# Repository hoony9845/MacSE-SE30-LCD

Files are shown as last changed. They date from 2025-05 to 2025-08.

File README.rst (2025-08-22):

MacSE-SE30-LCD
====================================================================

Links
-------
video: https://youtu.be/YyA7AwdUPjI

Reference
-------
https://github.com/aeberbach/MacSE-SE30-analog-replacement

https://github.com/guruthree/mac-se-video-converter

https://tinkerdifferent.com/threads/a-new-alternative-for-high-quality-video-output-on-your-compact-mac.3890/

Pictures
----------

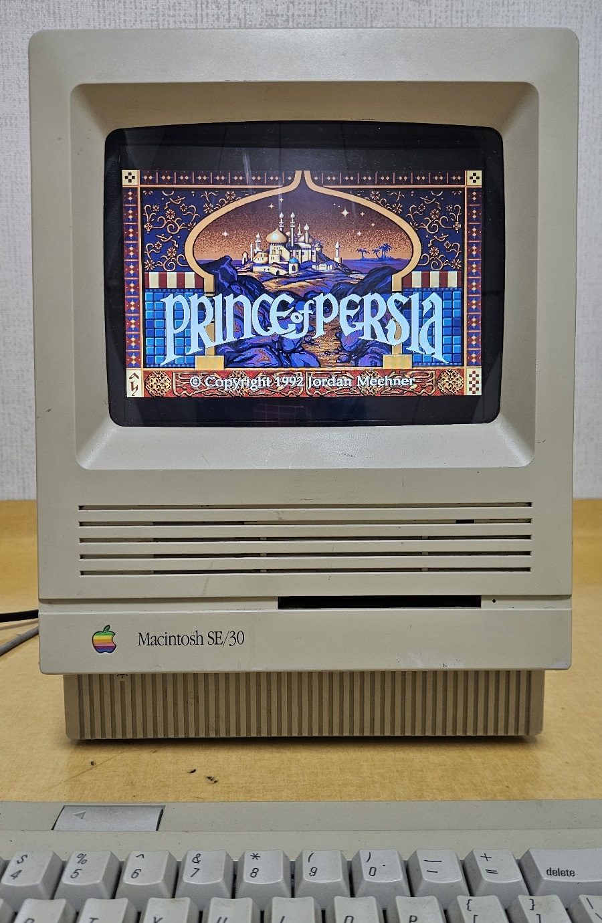
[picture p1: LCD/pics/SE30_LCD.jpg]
 

LCD
----
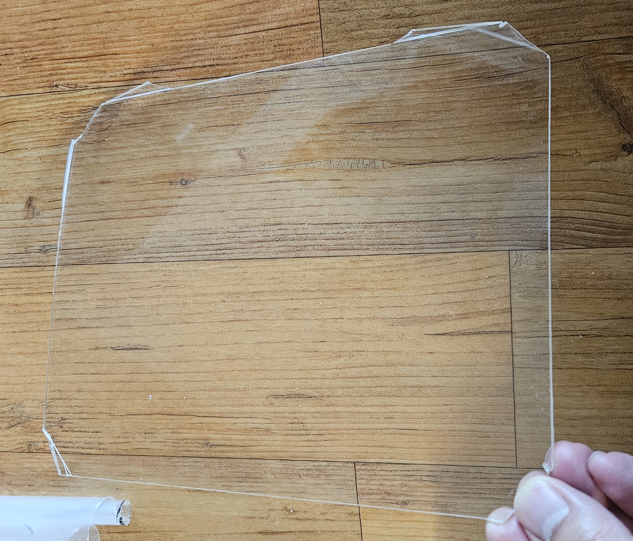
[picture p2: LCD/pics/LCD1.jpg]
 

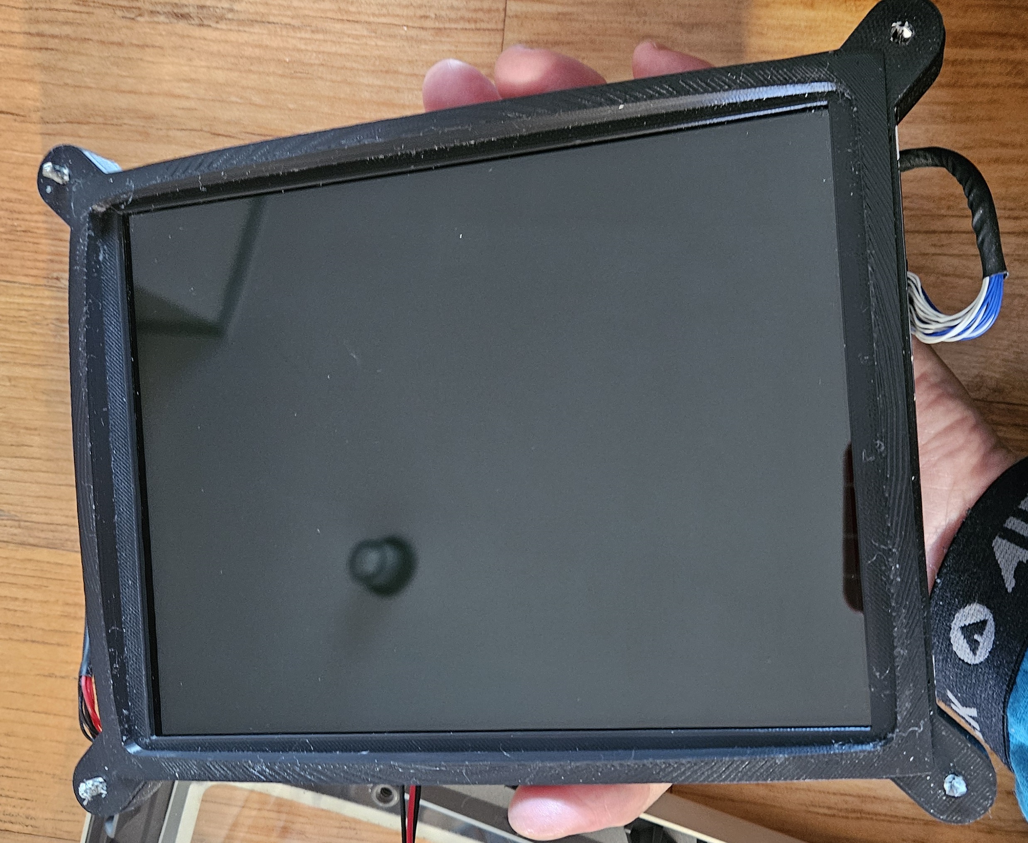
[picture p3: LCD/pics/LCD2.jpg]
 

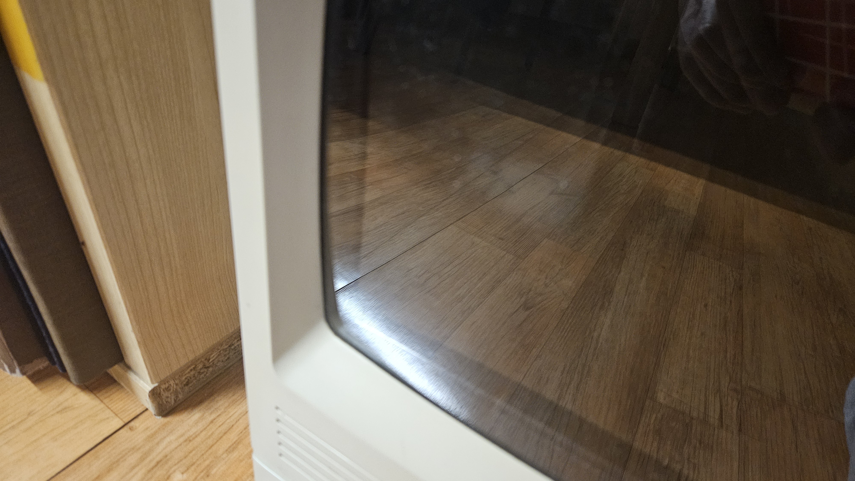
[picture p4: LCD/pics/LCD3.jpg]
 

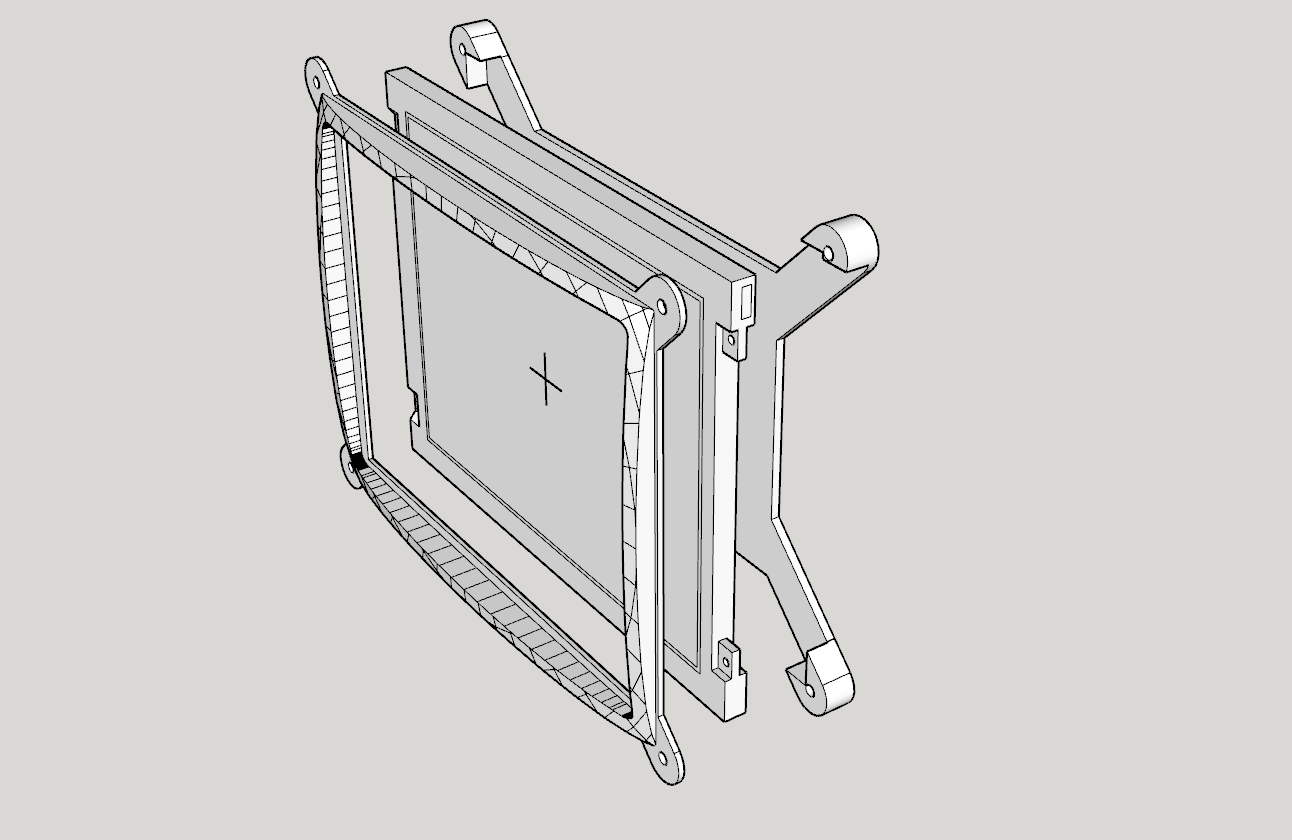
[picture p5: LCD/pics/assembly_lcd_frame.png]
 

Ananlog Board
----

It provides the following features:

- Can use the original PSU / the Mean Well PT-65B / ATX Power Supply

- A converter that can output the logic board's video signal to VGA (B/W, 800 x 640)

- Screen brightness control

- Fan RPM control

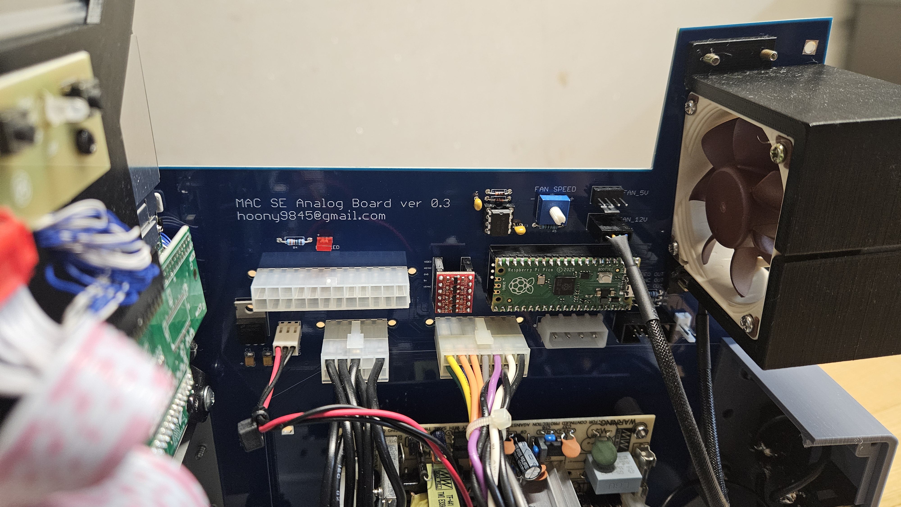
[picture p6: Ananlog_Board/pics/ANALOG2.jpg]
 
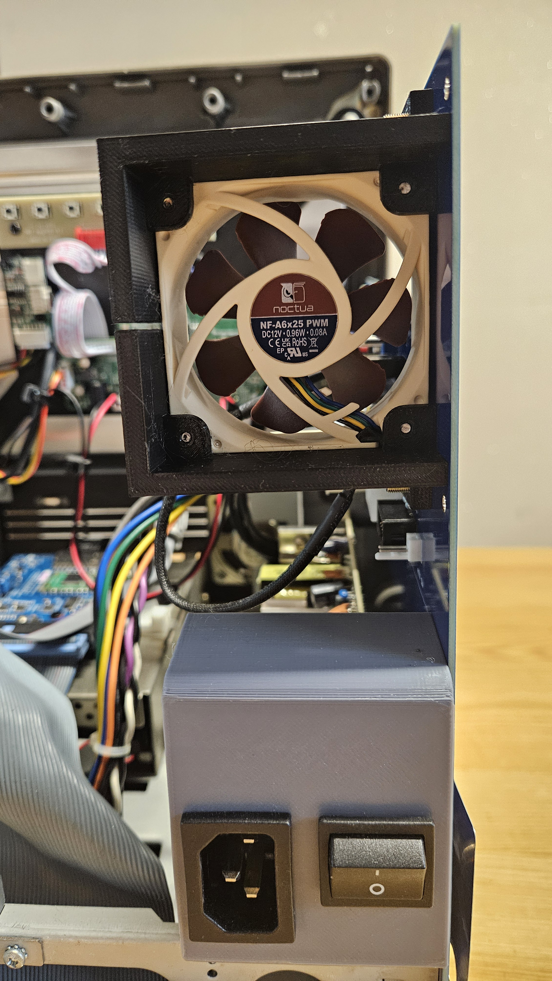
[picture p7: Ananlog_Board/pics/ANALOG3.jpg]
 

ver3.0 BOM
 ========= ============================== ==================================================================================================================================== 
  Part      Value                          link                                                                                                                                
 ========= ============================== ==================================================================================================================================== 
  ATX_SW    Molex 5045-02                  https://www.devicemart.co.kr/goods/view?no=1059947                                                                                  
  C1        Chip Tantal B size 2.2uF 35V   https://www.devicemart.co.kr/goods/view?no=38371                                                                                    
  C2        Chip Tantal B size 1uF 35V     https://www.devicemart.co.kr/goods/view?no=1111474                                                                                  
  C3        mono 10nF                      https://www.devicemart.co.kr/goods/view?no=1404                                                                                     
  C4        mono 1nF                       https://www.devicemart.co.kr/goods/view?no=1410                                                                                     
  D1        DIODE-1N4148                   https://www.devicemart.co.kr/goods/view?no=25                                                                                       
  D2        DIODE-1N4148                   https://www.devicemart.co.kr/goods/view?no=25                                                                                       
  IC1       7905CT                         https://www.devicemart.co.kr/goods/view?no=1057635                                                                                  
  J1        13MM, A103 A10K, Half-shaft    https://ko.aliexpress.com/item/1005007568562043.html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   
  J2        2X5P-2.54                      https://www.devicemart.co.kr/goods/view?no=248                                                                                      
  LCD       Molex 5045-03                  https://www.devicemart.co.kr/goods/view?no=1059948                                                                                  
  P1/P2     Level shifter                  https://www.devicemart.co.kr/goods/view?no=1324248                                                                                  
  PWR_LED   LED                            https://www.devicemart.co.kr/goods/view?no=2848                                                                                     
  R1        1/4W 100 ohm                   https://www.devicemart.co.kr/goods/view?no=1996                                                                                     
  R2        1/4W 68 ohm                    https://www.devicemart.co.kr/goods/view?no=1992                                                                                     
  R3        1/4W 68 ohm                    https://www.devicemart.co.kr/goods/view?no=1992                                                                                     
  R4        1/4W 330 ohm                   https://www.devicemart.co.kr/goods/view?no=2005                                                                                     
  R5        1/4W 1k ohm                    https://www.devicemart.co.kr/goods/view?no=2014                                                                                     
  U$2       RASPBERRY-PI-PICO              https://www.devicemart.co.kr/goods/view?no=13921792                                                                                 
  U1        350211-1                       https://www.devicemart.co.kr/goods/view?no=14581529                                                                                 
  U2        NE555N                         https://www.devicemart.co.kr/goods/view?no=1058745                                                                                  
  VR1       WIW3386P                       https://www.devicemart.co.kr/goods/view?no=37692                                                                                    
  X1        Molex 5566-10                  https://www.devicemart.co.kr/goods/view?no=352                                                                                      
  X2        Molex 5566-14                  https://www.devicemart.co.kr/goods/view?no=354                                                                                      
  X3        Molex 5566-24                  https://www.devicemart.co.kr/goods/view?no=358                                                                                      
  X4        KF2510 3+1                     https://ko.aliexpress.com/item/1005008137720976.html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    
  X5        KF2510 3+1                     https://ko.aliexpress.com/item/1005008137720976.html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    
 ========= ============================== ====================================================================================================================================

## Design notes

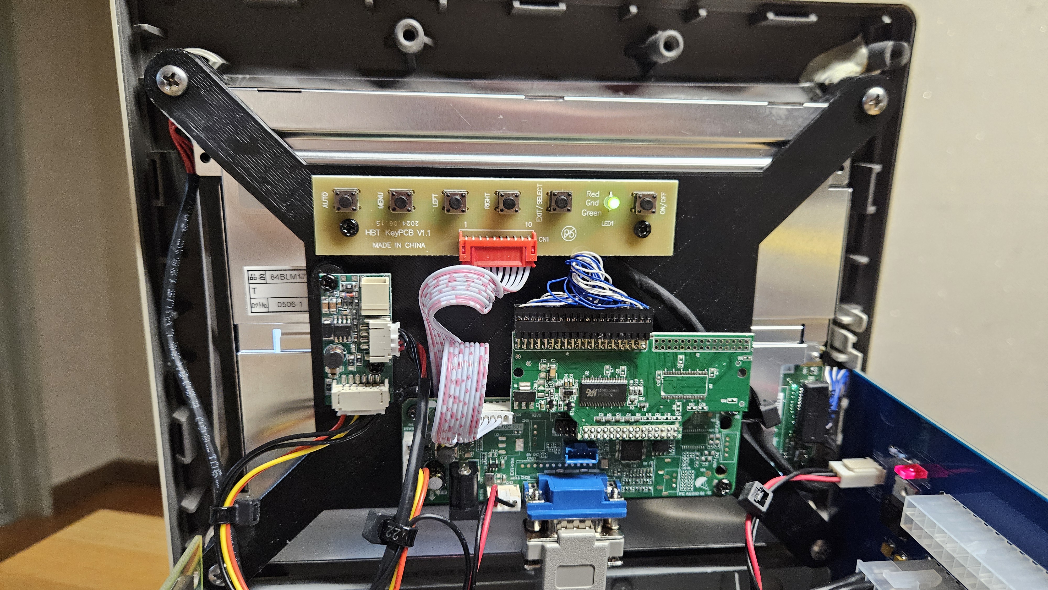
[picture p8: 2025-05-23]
LCD/pics/LCD4.jpg

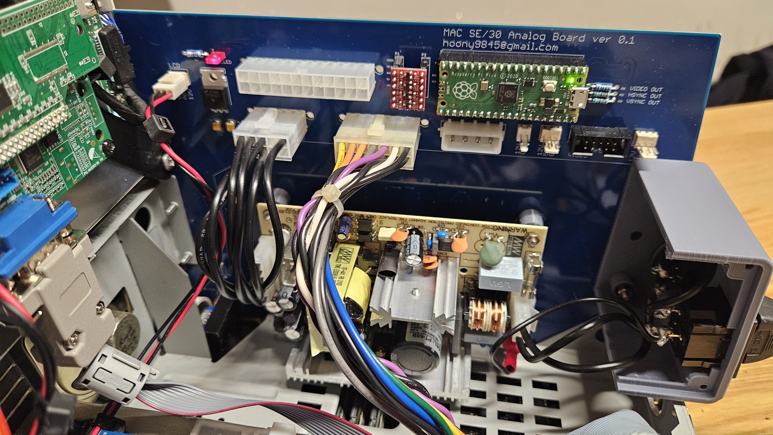
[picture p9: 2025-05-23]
Ananlog_Board/pics/ANALOG1.jpg

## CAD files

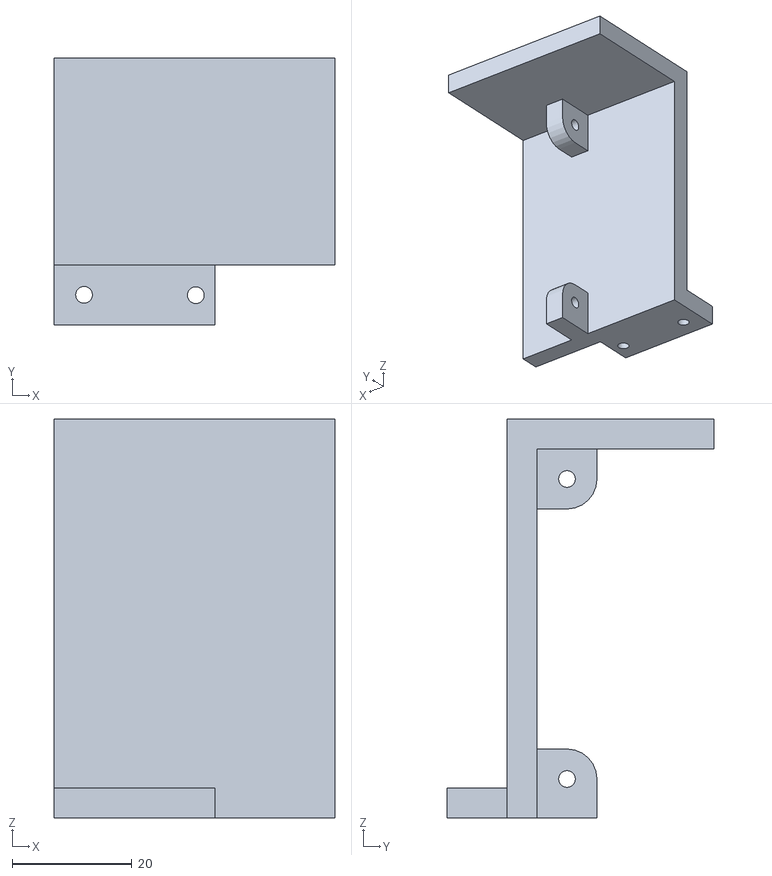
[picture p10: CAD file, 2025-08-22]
Ananlog_Board/stls/se30_fanmount1.stl
46.8 x 44.5 x 66.5

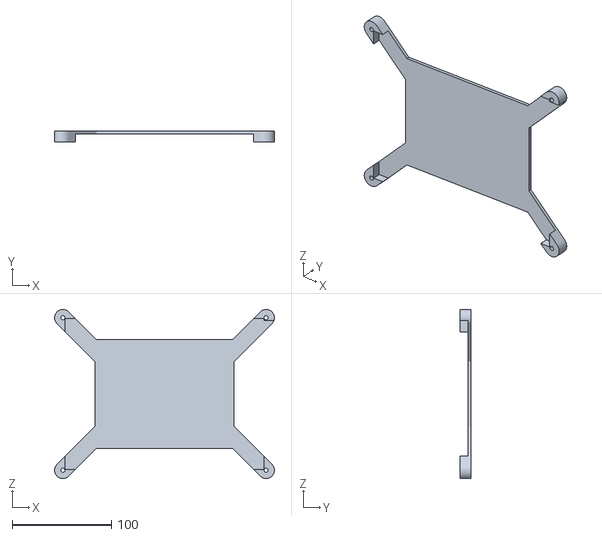
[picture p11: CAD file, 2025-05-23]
LCD/stls/SE30_LCD_2.stl
221.6 x 11.2 x 170.4

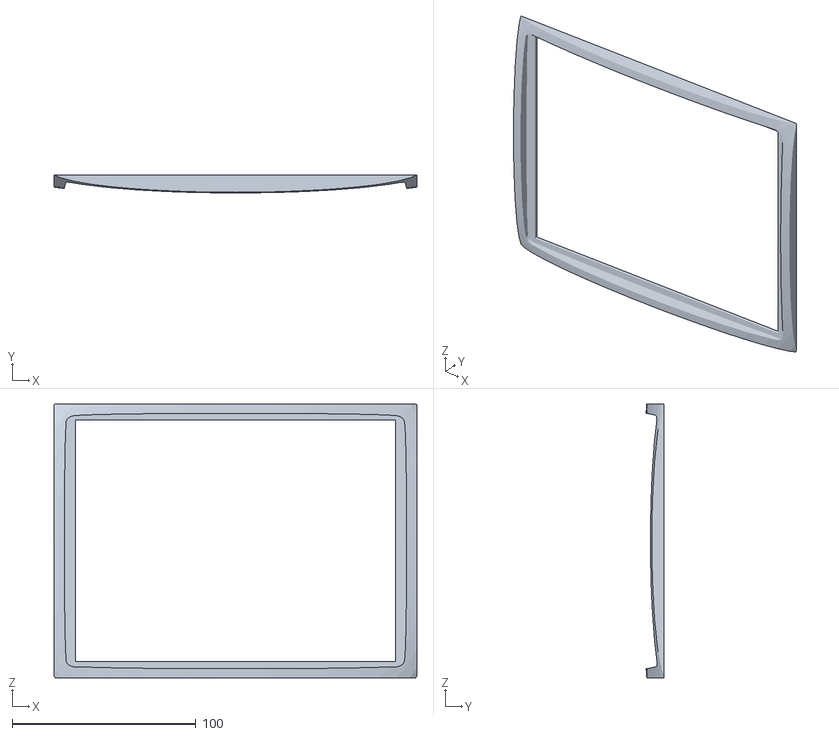
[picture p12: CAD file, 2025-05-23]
LCD/stls/SE30_LCD_1.stl
197.5 x 9.75 x 149.0

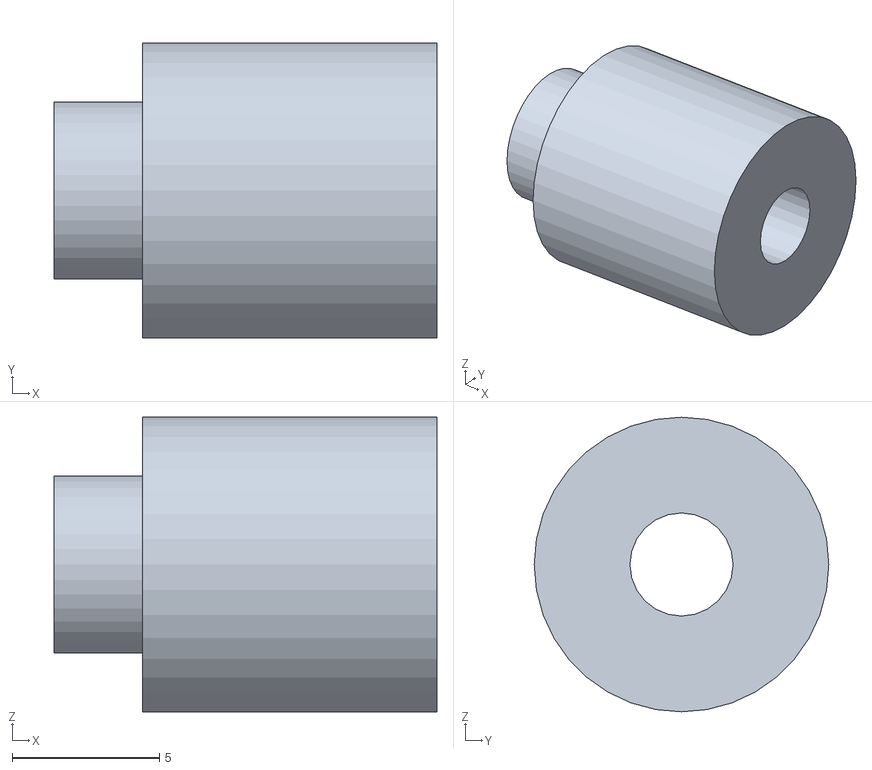
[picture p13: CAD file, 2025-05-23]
Ananlog_Board/stls/MW-PT-65B_psu_base.stl
13.0 x 10.0 x 10.0

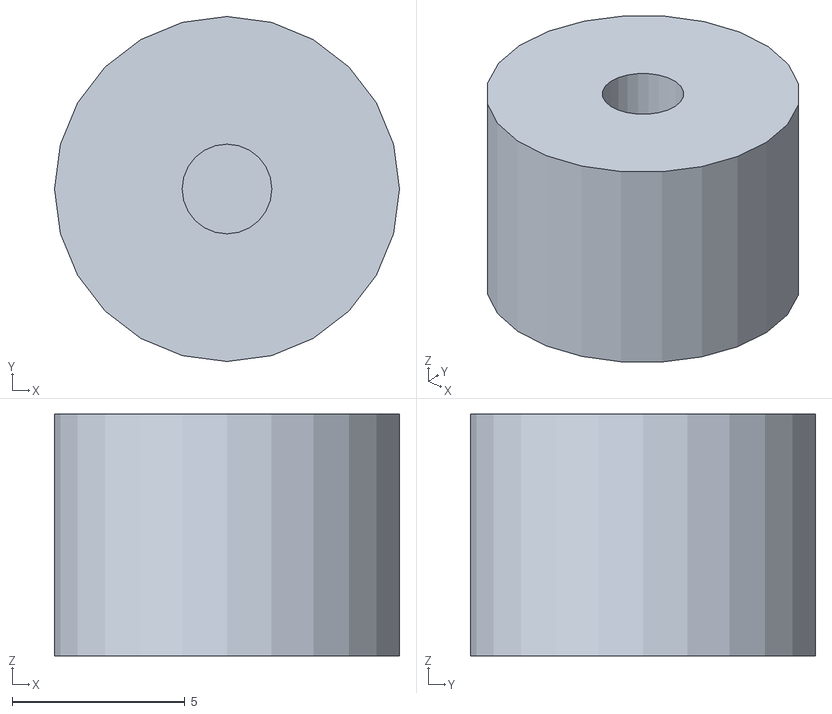
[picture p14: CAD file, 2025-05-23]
LCD/stls/SE30_LCD_3.stl
10.0 x 10.0 x 7.00

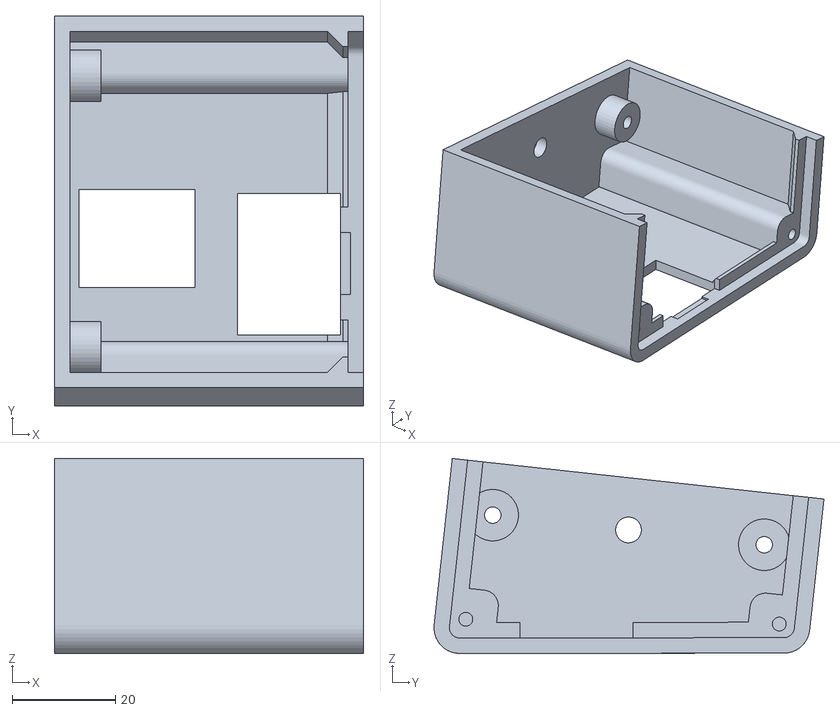
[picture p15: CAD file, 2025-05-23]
Ananlog_Board/stls/MW-PT-65B_switch_base.stl
60.0 x 75.7 x 37.8

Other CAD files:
Ananlog_Board/stls/se30_fanmount2.stl
Ananlog_Board/stls/Als_RK11K_A10K_13mm_Half_Shaft.stl

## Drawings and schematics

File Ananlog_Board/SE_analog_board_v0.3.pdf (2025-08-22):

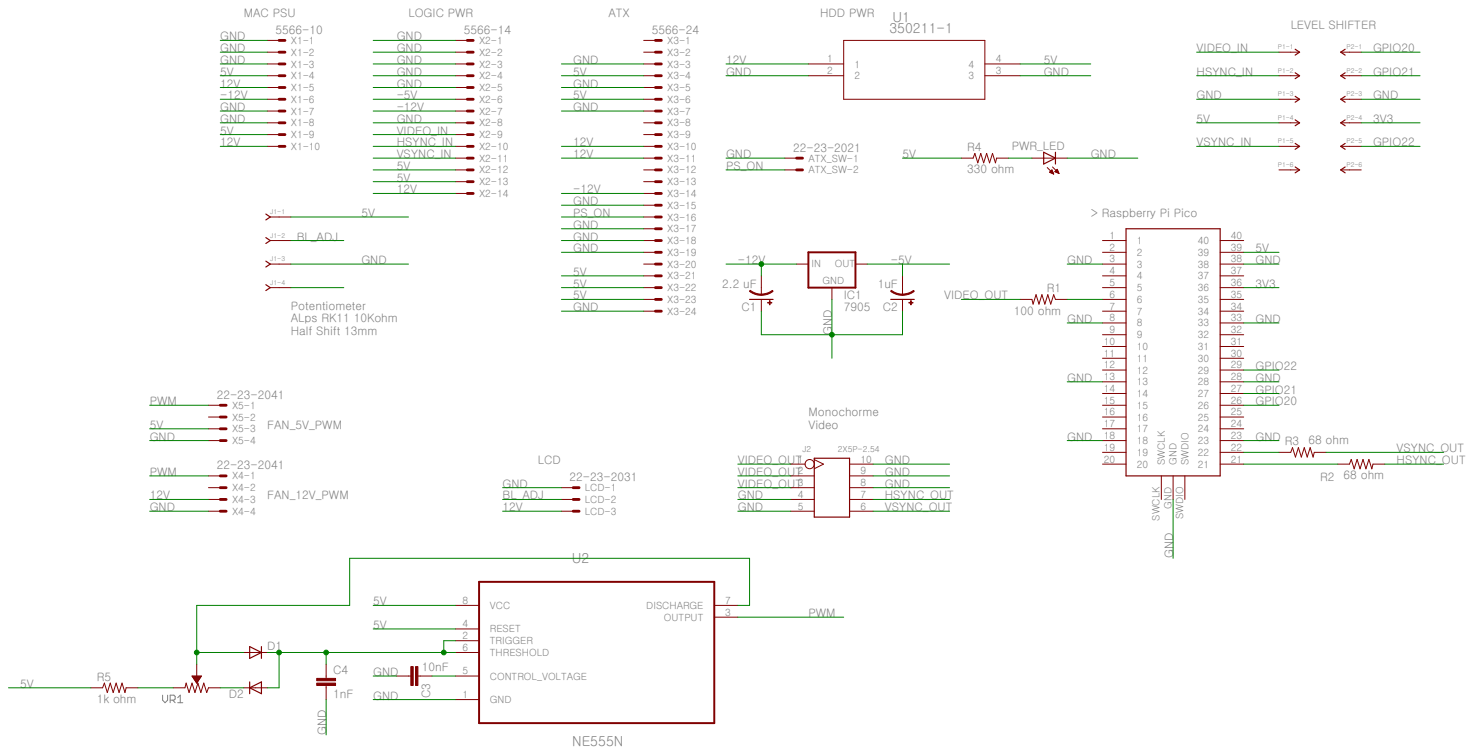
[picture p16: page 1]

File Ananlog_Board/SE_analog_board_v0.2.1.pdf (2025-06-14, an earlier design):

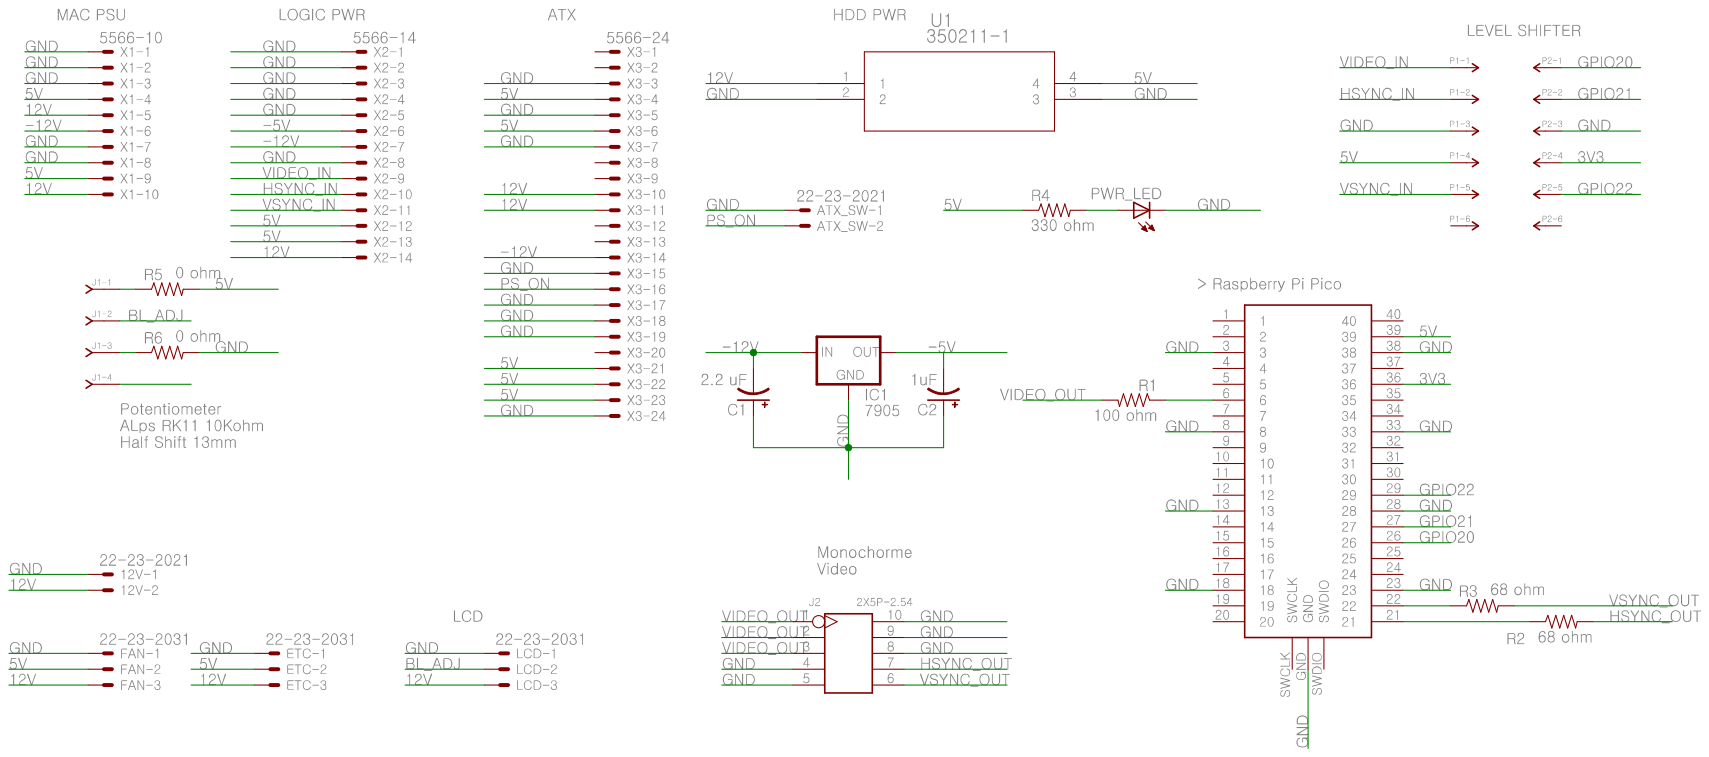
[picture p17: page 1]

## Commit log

2025-05-23 Add init data
    [Als_RK11K_A10K_13mm_Half_Shaft.stl, MW-PT-65B_psu_base.stl, MW-PT-65B_switch_base.stl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]
2025-05-23 Added Analog board firmware
2025-08-11 Update README.rst
    Add BOM
2025-08-22 Added schematic and gerber of version 0.3
2025-08-22 Added STL files for fan mount.
    [se30_fanmount1.stl, se30_fanmount2.stl]
